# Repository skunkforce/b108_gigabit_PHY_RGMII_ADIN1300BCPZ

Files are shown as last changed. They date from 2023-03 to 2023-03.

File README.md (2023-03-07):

# edgy_board number b108
This design is part of the [edgy board project](https://github.com/skunkforce/edgy_boards).

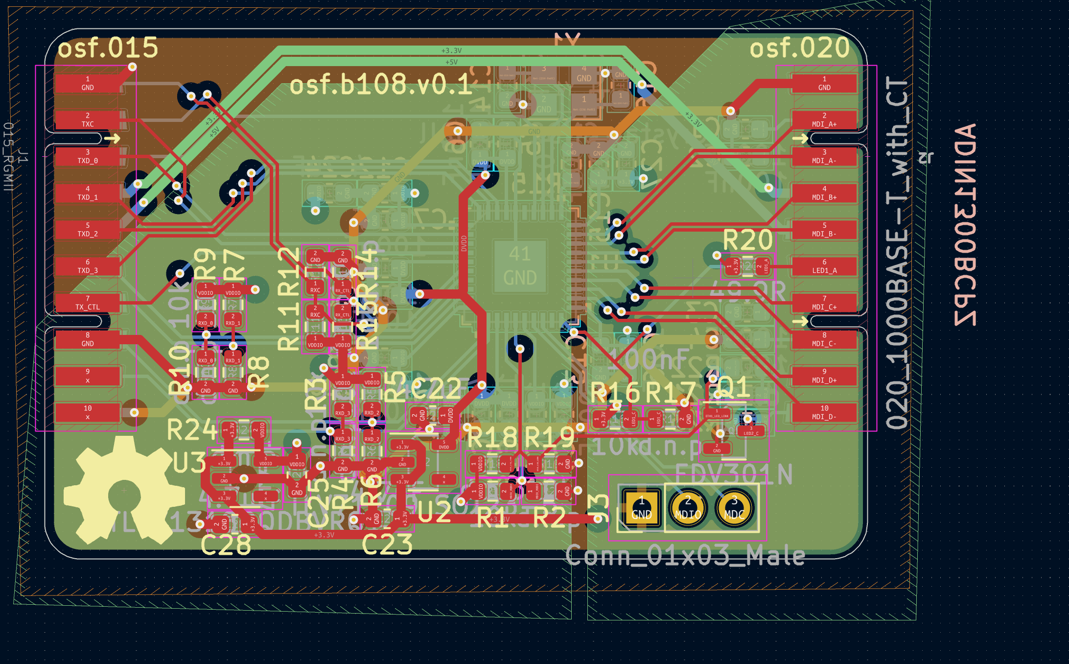
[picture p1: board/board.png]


# getting started
This repository uses submodules. After cloning use the command 

```$ git submodule update --init --recursive```

to pull the submodules before opening the project with kicad. 

# Tests
Tests can be found in [TESTS.md](TESTS.md)

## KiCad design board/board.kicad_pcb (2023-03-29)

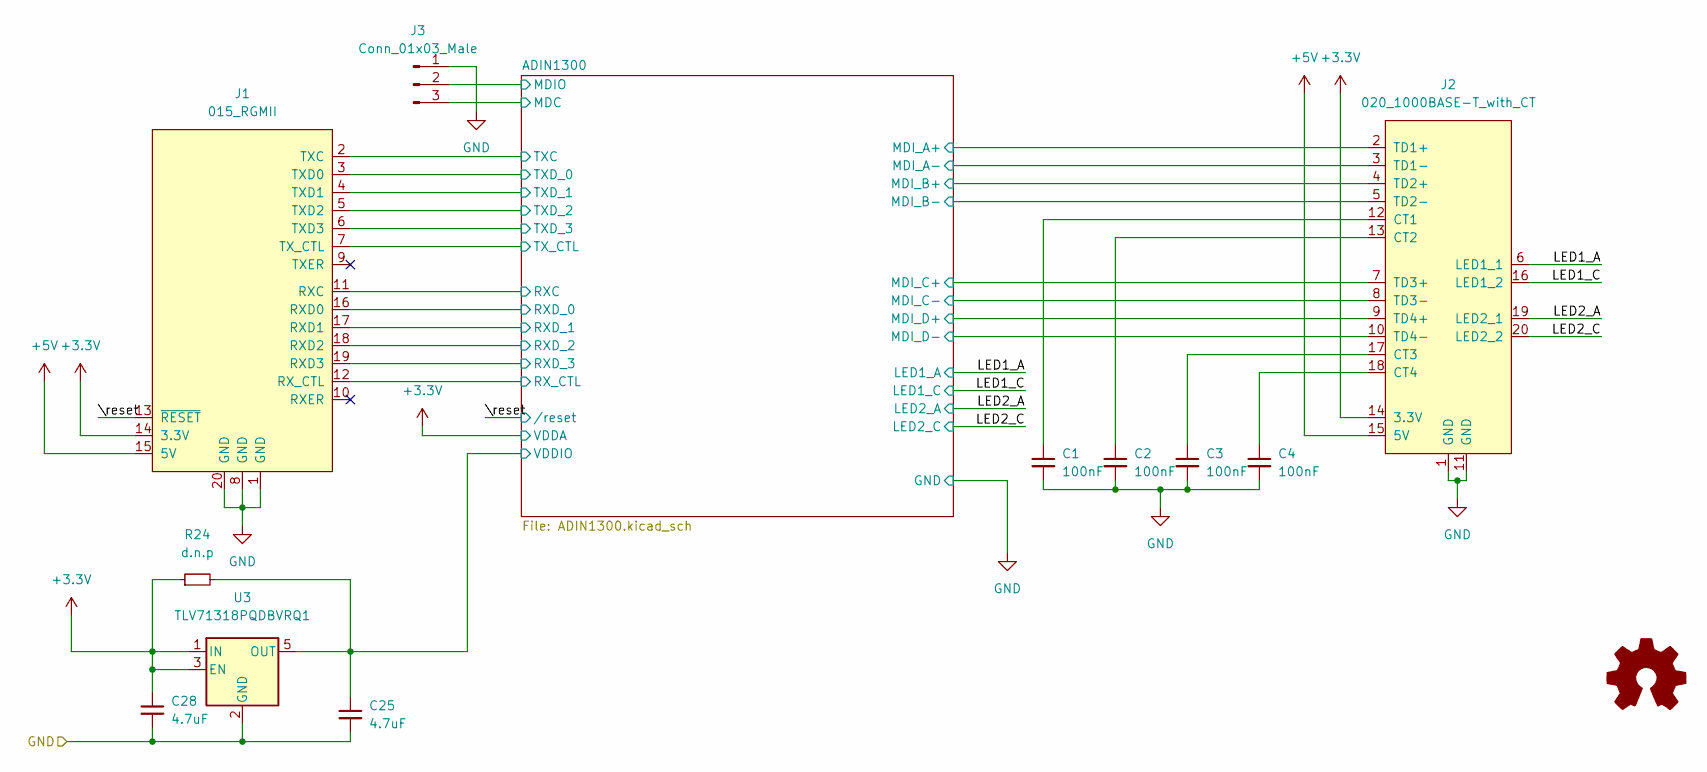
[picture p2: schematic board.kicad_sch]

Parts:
C1, C2, C3, C4: 100nF; C_0603_1608Metric
C25, C28: 4.7uF; C_0603_1608Metric
J1: 015_RGMII; on_edge_2x10_device
J2: 020_1000BASE-T_with_CT; on_edge_2x10_host
J3: Conn_01x03_Male; PinHeader_1x03_P2.54mm_Vertical
LOGO1: Logo_Open_Hardware_Small; OSHW-Symbol_6.7x6mm_SilkScreen
R24: d.n.p; R_0603_1608Metric
U3: TLV71318PQDBVRQ1; SOT-23-5; MPN TLV71318PQDBVRQ1; Digi-Key_PN 296-42363-1-ND

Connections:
+3.3V: C28.1, J1.14 (3.3V), J2.14 (3.3V), R24.1, U3.1 (IN), U3.3 (EN); also elsewhere on the board
+5V: J1.15 (5V), J2.15 (5V)
/ADIN1300/MDC: J3.3; also elsewhere on the board
/ADIN1300/MDIO: J3.2; also elsewhere on the board
/ADIN1300/MDI_A+: J2.2 (TD1+); also elsewhere on the board
/ADIN1300/MDI_A-: J2.3 (TD1-); also elsewhere on the board
/ADIN1300/MDI_B+: J2.4 (TD2+); also elsewhere on the board
/ADIN1300/MDI_B-: J2.5 (TD2-); also elsewhere on the board
/ADIN1300/MDI_C+: J2.7 (TD3+); also elsewhere on the board
/ADIN1300/MDI_C-: J2.8 (TD3-); also elsewhere on the board
/ADIN1300/MDI_D+: J2.9 (TD4+); also elsewhere on the board
/ADIN1300/MDI_D-: J2.10 (TD4-); also elsewhere on the board
/ADIN1300/RXC: J1.11 (RXC); also elsewhere on the board
/ADIN1300/RXD_0: J1.16 (RXD0); also elsewhere on the board
/ADIN1300/RXD_1: J1.17 (RXD1); also elsewhere on the board
/ADIN1300/RXD_2: J1.18 (RXD2); also elsewhere on the board
/ADIN1300/RXD_3: J1.19 (RXD3); also elsewhere on the board
/ADIN1300/RX_CTL: J1.12 (RX_CTL); also elsewhere on the board
/ADIN1300/TXC: J1.2 (TXC); also elsewhere on the board
/ADIN1300/TXD_0: J1.3 (TXD0); also elsewhere on the board
/ADIN1300/TXD_1: J1.4 (TXD1); also elsewhere on the board
/ADIN1300/TXD_2: J1.5 (TXD2); also elsewhere on the board
/ADIN1300/TXD_3: J1.6 (TXD3); also elsewhere on the board
/ADIN1300/TX_CTL: J1.7 (TX_CTL); also elsewhere on the board
/ADIN1300/VDDIO: C25.1, R24.2, U3.5 (OUT); also elsewhere on the board
/LED1_A: J2.6 (LED1_1); also elsewhere on the board
/LED1_C: J2.16 (LED1_2); also elsewhere on the board
/LED2_A: J2.19 (LED2_1); also elsewhere on the board
/LED2_C: J2.20 (LED2_2); also elsewhere on the board
/\reset: J1.13 (~RESET); also elsewhere on the board
GND: C1.2, C2.2, C3.2, C4.2, C25.2, C28.2, J1.1 (GND), J1.8 (GND), J1.20 (GND), J2.1 (GND), J2.11 (GND), J3.1, U3.2 (GND); also elsewhere on the board
unnamed: C1.1, J2.12 (CT1)
unnamed: C2.1, J2.13 (CT2)
unnamed: C3.1, J2.17 (CT3)
unnamed: C4.1, J2.18 (CT4)

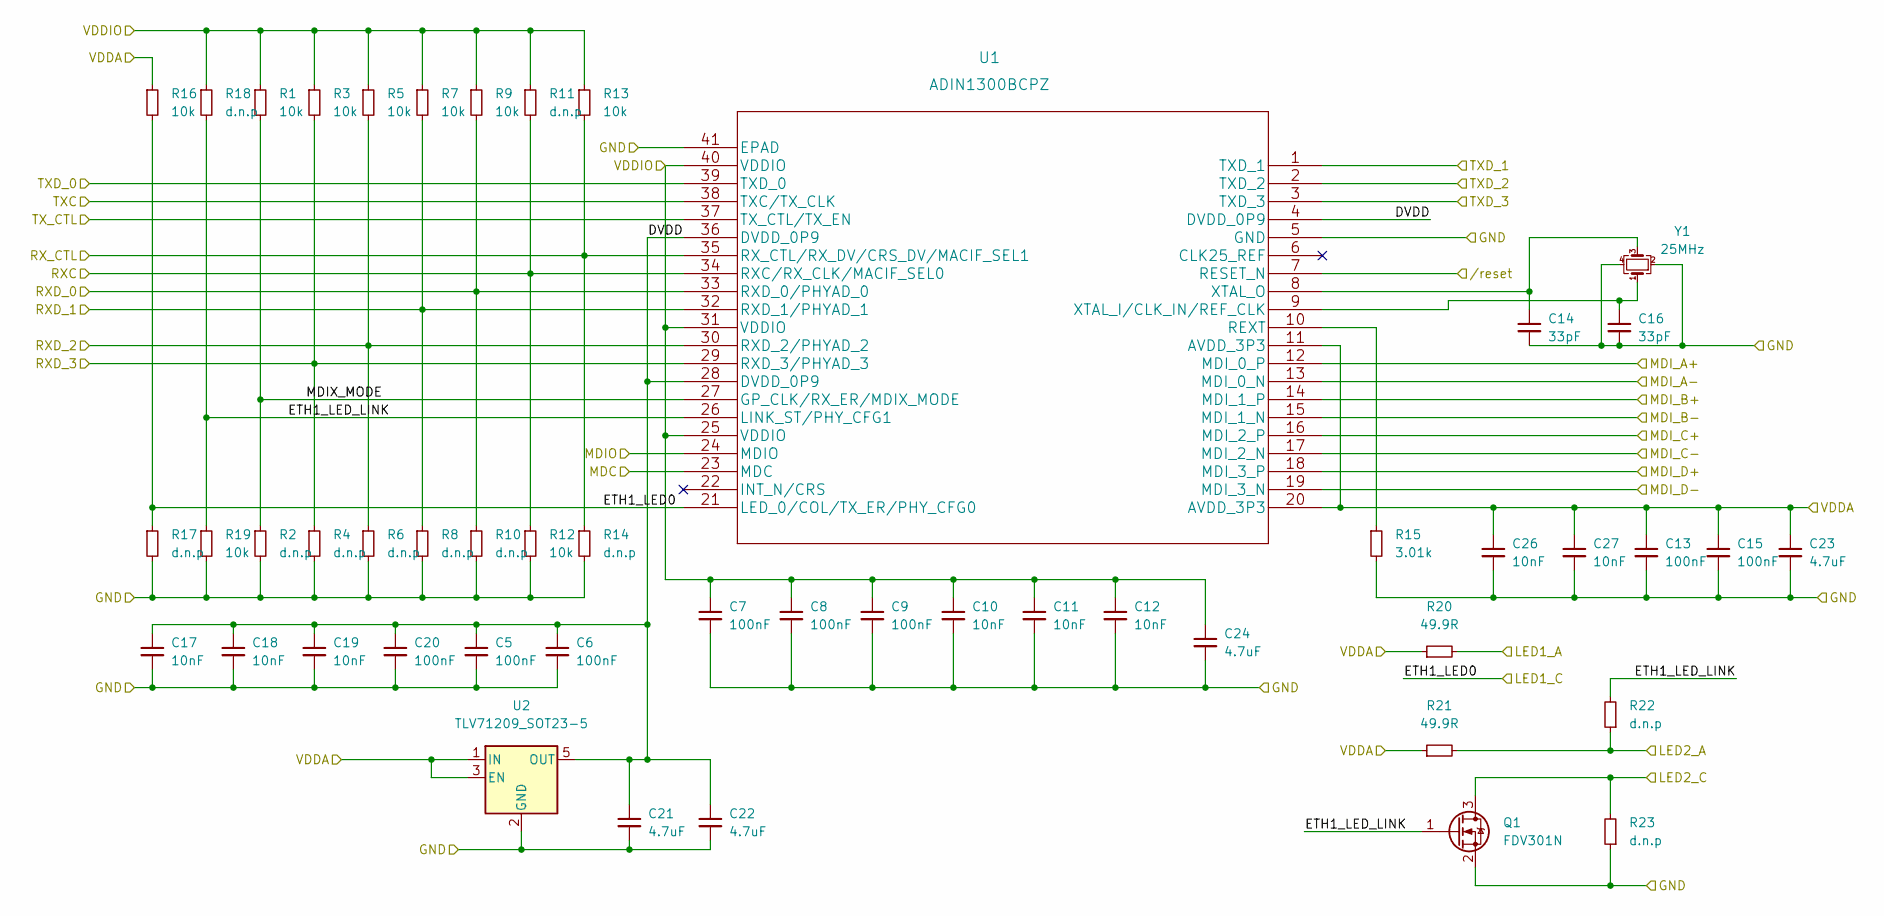
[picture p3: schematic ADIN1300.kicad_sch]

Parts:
C5, C6, C7, C8, C9, C13, C15, C20: 100nF; C_0603_1608Metric
C10, C11, C12, C17, C18, C19, C26, C27: 10nF; C_0603_1608Metric
C14, C16: 33pF; C_0603_1608Metric
C21, C22, C23, C24: 4.7uF; C_0603_1608Metric
Q1: FDV301N; SOT-23; MPN FDV301N; Digi-Key_PN FDV301NCT-ND
R1, R3, R5, R7, R9, R12, R13, R16, R19: 10k; R_0603_1608Metric
R2, R4, R6, R8, R10, R11, R14, R17, R18, R22, R23: d.n.p; R_0603_1608Metric
R15: 3.01k; R_0603_1608Metric
R20, R21: 49.9R; R_0603_1608Metric
U1: ADIN1300BCPZ
U2: TLV71209_SOT23-5; SOT-23-5
Y1: 25MHz; Crystal_SMD_Abracon_ABM8G-4Pin_3.2x2.5mm

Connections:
+3.3V: C13.1, C15.1, C23.1, C26.1, C27.1, R16.1, R20.1, R21.1, U1.11 (AVDD_3P3), U1.20 (AVDD_3P3), U2.1 (IN), U2.3 (EN); also elsewhere on the board
/ADIN1300/DVDD: C5.1, C6.1, C17.1, C18.1, C19.1, C20.1, C21.1, C22.1, U1.4 (DVDD_0P9), U1.28 (DVDD_0P9), U1.36 (DVDD_0P9), U2.5 (OUT)
/ADIN1300/ETH1_LED_LINK: Q1.1 (G), R18.2, R19.1, R22.2, U1.26 (LINK_ST/PHY_CFG1)
/ADIN1300/MDC: U1.23 (MDC); also elsewhere on the board
/ADIN1300/MDIO: U1.24 (MDIO); also elsewhere on the board
/ADIN1300/MDIX_MODE: R1.2, R2.1, U1.27 (GP_CLK/RX_ER/MDIX_MODE)
/ADIN1300/MDI_A+: U1.12 (MDI_0_P); also elsewhere on the board
/ADIN1300/MDI_A-: U1.13 (MDI_0_N); also elsewhere on the board
/ADIN1300/MDI_B+: U1.14 (MDI_1_P); also elsewhere on the board
/ADIN1300/MDI_B-: U1.15 (MDI_1_N); also elsewhere on the board
/ADIN1300/MDI_C+: U1.16 (MDI_2_P); also elsewhere on the board
/ADIN1300/MDI_C-: U1.17 (MDI_2_N); also elsewhere on the board
/ADIN1300/MDI_D+: U1.18 (MDI_3_P); also elsewhere on the board
/ADIN1300/MDI_D-: U1.19 (MDI_3_N); also elsewhere on the board
/ADIN1300/RXC: R11.2, R12.1, U1.34 (RXC/RX_CLK/MACIF_SEL0); also elsewhere on the board
/ADIN1300/RXD_0: R9.2, R10.1, U1.33 (RXD_0/PHYAD_0); also elsewhere on the board
/ADIN1300/RXD_1: R7.2, R8.1, U1.32 (RXD_1/PHYAD_1); also elsewhere on the board
/ADIN1300/RXD_2: R5.2, R6.1, U1.30 (RXD_2/PHYAD_2); also elsewhere on the board
/ADIN1300/RXD_3: R3.2, R4.1, U1.29 (RXD_3/PHYAD_3); also elsewhere on the board
/ADIN1300/RX_CTL: R13.2, R14.1, U1.35 (RX_CTL/RX_DV/CRS_DV/MACIF_SEL1); also elsewhere on the board
/ADIN1300/TXC: U1.38 (TXC/TX_CLK); also elsewhere on the board
/ADIN1300/TXD_0: U1.39 (TXD_0); also elsewhere on the board
/ADIN1300/TXD_1: U1.1 (TXD_1); also elsewhere on the board
/ADIN1300/TXD_2: U1.2 (TXD_2); also elsewhere on the board
/ADIN1300/TXD_3: U1.3 (TXD_3); also elsewhere on the board
/ADIN1300/TX_CTL: U1.37 (TX_CTL/TX_EN); also elsewhere on the board
/ADIN1300/VDDIO: C7.1, C8.1, C9.1, C10.1, C11.1, C12.1, C24.1, R1.1, R3.1, R5.1, R7.1, R9.1, R11.1, R13.1, R18.1, U1.25 (VDDIO), U1.31 (VDDIO), U1.40 (VDDIO); also elsewhere on the board
/LED1_A: R20.2; also elsewhere on the board
/LED1_C: R16.2, R17.1, U1.21 (LED_0/COL/TX_ER/PHY_CFG0); also elsewhere on the board
/LED2_A: R21.2, R22.1; also elsewhere on the board
/LED2_C: Q1.3 (D), R23.2; also elsewhere on the board
/\reset: U1.7 (RESET_N); also elsewhere on the board
GND: C5.2, C6.2, C7.2, C8.2, C9.2, C10.2, C11.2, C12.2, C13.2, C14.2, C15.2, C16.2, C17.2, C18.2, C19.2, C20.2, C21.2, C22.2, C23.2, C24.2, C26.2, C27.2, Q1.2 (S), R2.2, R4.2, R6.2, R8.2, R10.2, R12.2, R14.2, R15.2, R17.2, R19.2, R23.1, U1.5 (GND), U1.41 (EPAD), U2.2 (GND), Y1.2, Y1.4; also elsewhere on the board
unnamed: C14.1, U1.8 (XTAL_O), Y1.3
unnamed: C16.1, U1.9 (XTAL_I/CLK_IN/REF_CLK), Y1.1
unnamed: R15.1, U1.10 (REXT)

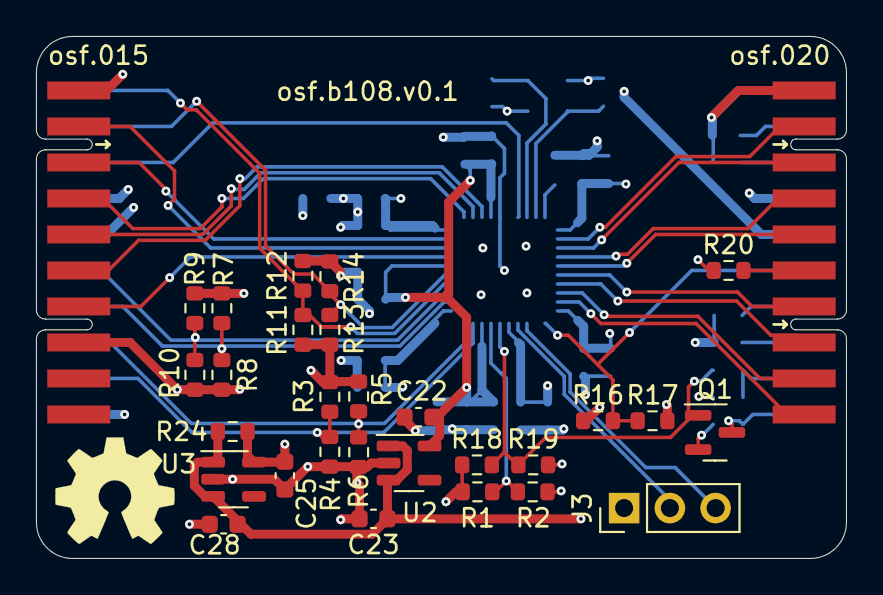
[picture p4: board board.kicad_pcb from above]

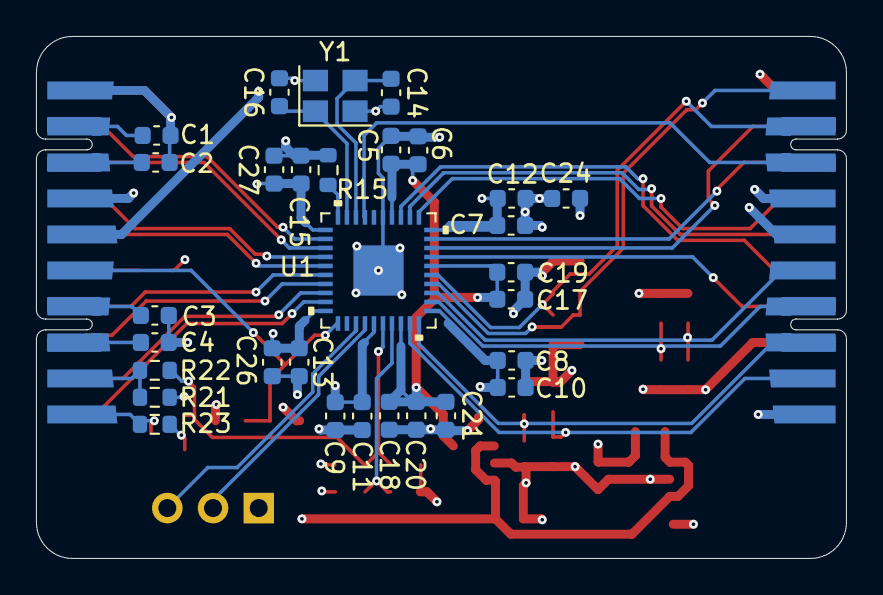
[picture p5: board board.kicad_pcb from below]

Board: 4 copper layers, 45.0 x 29.0 mm, 61 parts (30 on the bottom side), 41 nets.

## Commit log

2023-03-08 optimized EMI
    [ADIN1300.kicad_sch, board.kicad_pcb, board.kicad_sch]
2023-03-29 specified crystal frequentcy
    [ADIN1300.kicad_sch, board.kicad_pcb, board.kicad_sch]
